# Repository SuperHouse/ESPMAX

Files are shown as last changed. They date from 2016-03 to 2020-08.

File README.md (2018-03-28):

ESP Max Prototyping Board
=========================

Copyright 2016 SuperHouse Automation Pty Ltd www.superhouse.tv  

Prototyping board for IoT projects using the ESP8266 microcontroller
on the ESP-12E module.

Features:

 * CP2102 USB-to-Serial converter.
 * 12 digital I/O channels at 3.3V.
 * 1 analog input with 0-3.2V range.
 * Power from USB or DC IN
 * 5V and 3.3V voltage regulators.
 * Jumper to select power source.
 * Prototyping area.
 * Expansion headers in D1 Mini format to suit expansion shields.

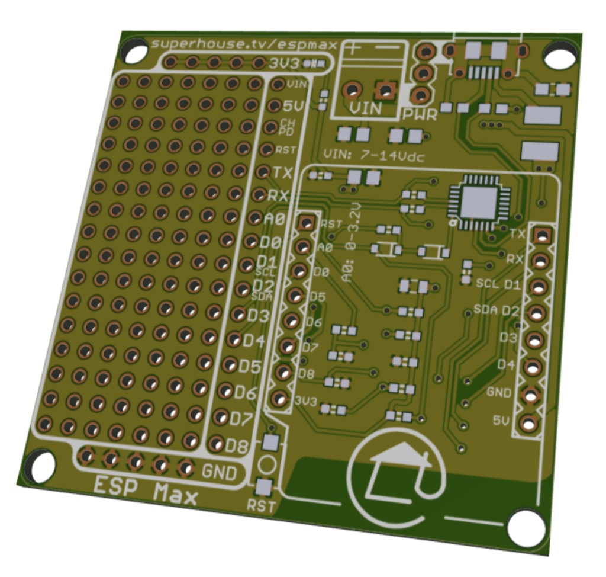
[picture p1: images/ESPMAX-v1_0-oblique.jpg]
Oblique view


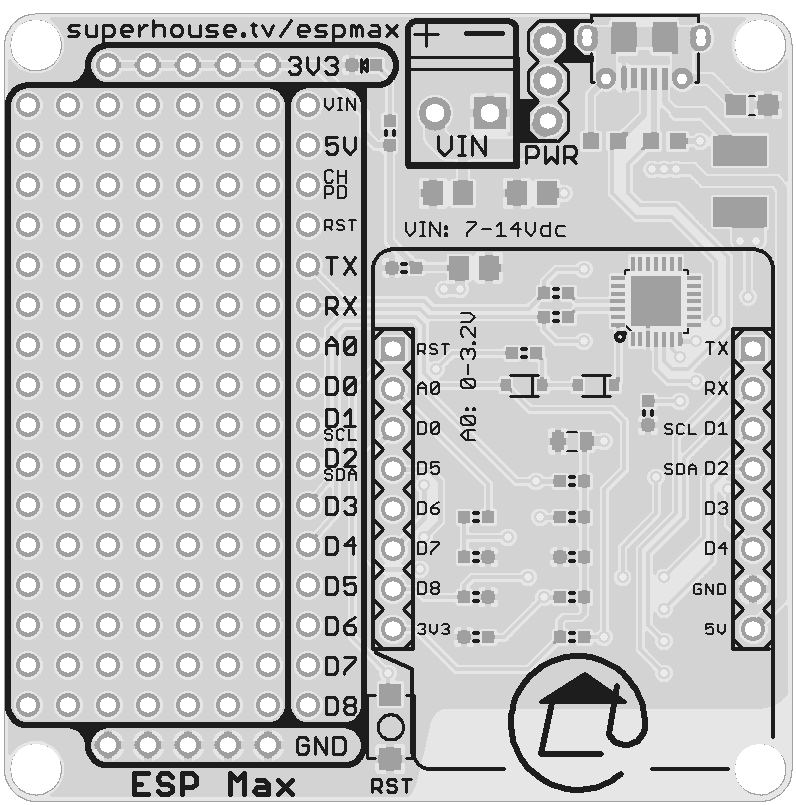
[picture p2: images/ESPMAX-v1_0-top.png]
Top view


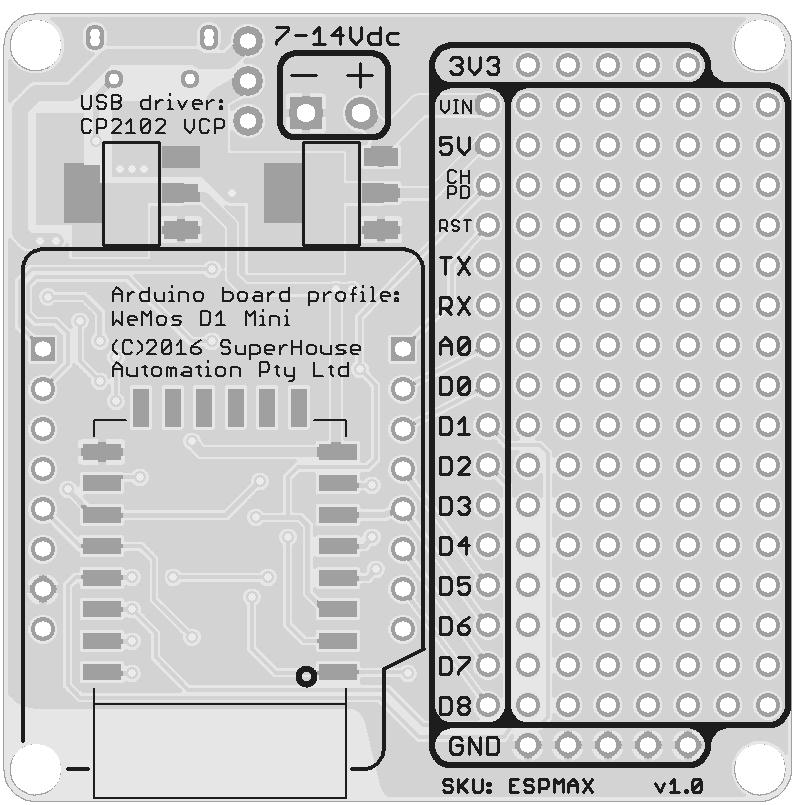
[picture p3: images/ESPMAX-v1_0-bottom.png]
Bottom view


More information is available at:

  http://www.superhouse.tv/espmax

INSTALLATION
------------
The design is saved as an EAGLE project. EAGLE PCB design software is
available from www.cadsoftusa.com free for non-commercial use. To use
this project download it and place the directory containing these files
into the "eagle" directory on your computer.

DISTRIBUTION
------------
The specific terms of distribution of this project are governed by the
license referenced below.

LICENSE
-------
Licensed under the TAPR Open Hardware License (www.tapr.org/OHL).
The "license" folder within this repository also contains a copy of
this license in plain text format.

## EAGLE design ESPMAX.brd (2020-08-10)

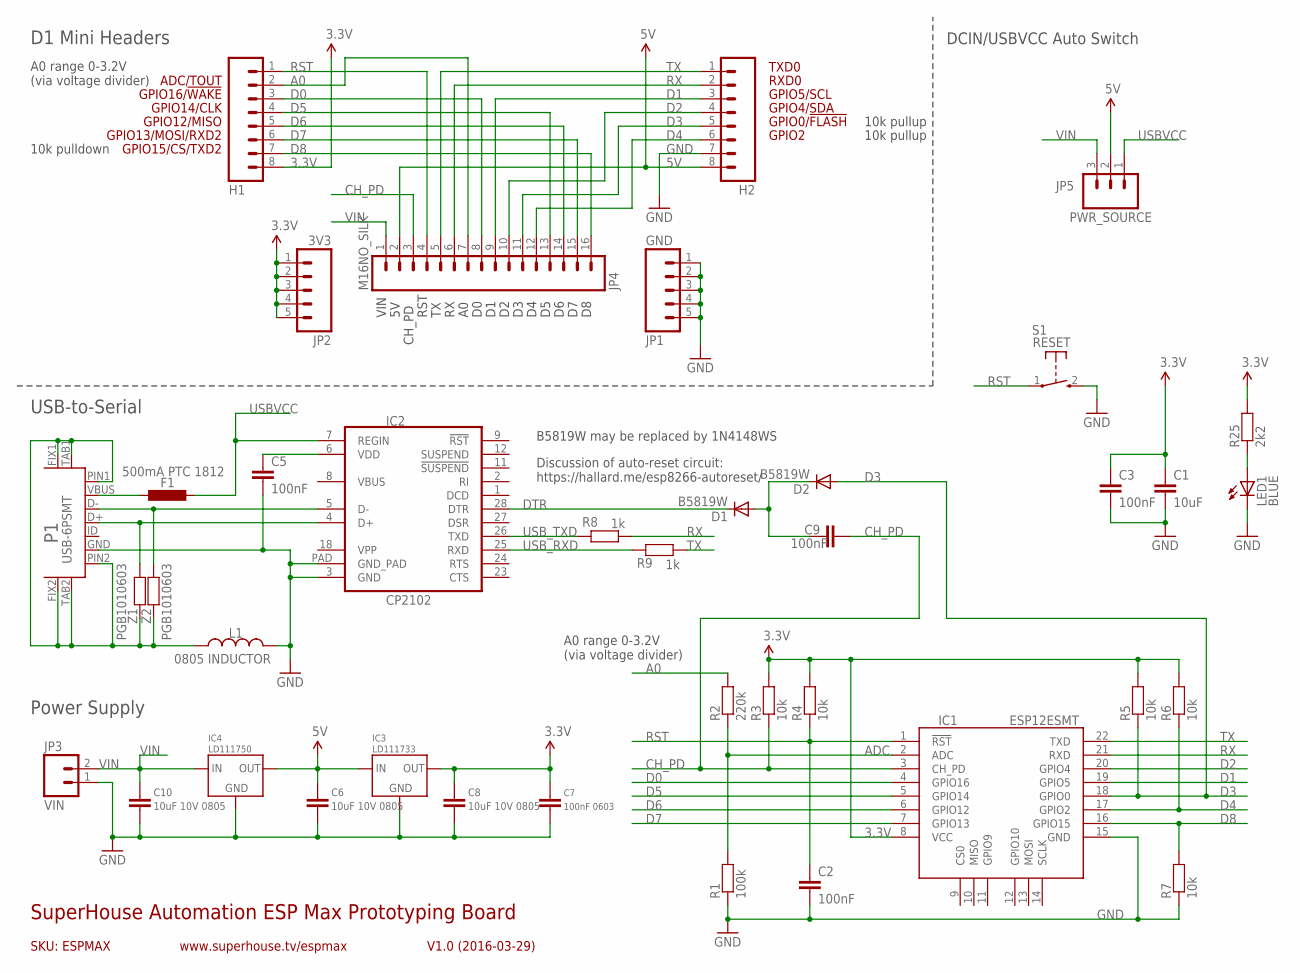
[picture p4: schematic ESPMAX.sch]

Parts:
C1: 10uF; 0805
C2, C3, C5, C9: 100nF; 0603
C6, C8, C10: 10uF 10V 0805; C0805
C7: 100nF 0603; 0603
D1, D2: B5819W; SOD-323
F1: 500mA PTC 1812; L1812
H1, H2: M08; 1X08
IC1: ESP12ESMT; ESP12E
IC2: CP2102; QFN-28
IC3: LD111733; SOT-223
IC4: LD111750; SOT-223
JP1: GND; 1X05_NO_SILK
JP2: 3V3; 1X05_NO_SILK
JP3: VIN; SCREWTERMINAL-3.5MM-2
JP4: M16NO_SILK; 1X16_NO_SILK
JP5: PWR_SOURCE; 1X03
L1: 0805 INDUCTOR; 0805-LARGE
LED1: BLUE; LED-0603
P1: USB-6PSMT; USB-MICROB-MB05PMXX
R1: 100k; 0603
R2: 220k; 0603
R3, R4, R5, R6, R7: 10k; 0603
R8, R9: 1k; 0603
R25: 2k2; 0603
S1: RESET; TACTILE_SWITCH_SMD_2PIN_TINY
Z1, Z2: PGB1010603; 0603

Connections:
3.3V: C1.1, C3.1, C7.1, C8.1, H1.8, IC1.8 (VCC), IC3.2 (OUT), IC3.4 (OUT), JP2.1, JP2.2, JP2.3, JP2.4, JP2.5, R3.2, R4.2, R5.2, R6.2, R25.2
5V: C6.1, H2.8, IC3.3 (IN), IC4.2 (OUT), IC4.4 (OUT), JP4.2, JP5.2
A0: H1.2, JP4.7, R2.2
ADC: IC1.2 (ADC), R1.2, R2.1
CH_PD: C9.2, IC1.3 (CH_PD), JP4.3, R3.1
D0: H1.3, IC1.4 (GPIO16), JP4.8
D1: H2.3, IC1.19 (GPIO5), JP4.9
D2: H2.4, IC1.20 (GPIO4), JP4.10
D3: D2.2 (A), H2.5, IC1.18 (GPIO0), JP4.11, R5.1
D4: H2.6, IC1.17 (GPIO2), JP4.12, R6.1
D5: H1.4, IC1.5 (GPIO14), JP4.13
D6: H1.5, IC1.6 (GPIO12), JP4.14
D7: H1.6, IC1.7 (GPIO13), JP4.15
D8: H1.7, IC1.16 (GPIO15), JP4.16, R7.2
DTR: D1.1 (C), IC2.28 (DTR)
GND: C1.2, C2.2, C3.2, C5.2, C6.2, C7.2, C8.2, C10.2, H2.7, IC1.15 (GND), IC2.3 (GND), IC2.PAD (GND_PAD), IC3.1 (GND), IC4.1 (GND), JP1.1, JP1.2, JP1.3, JP1.4, JP1.5, JP3.1, L1.2, LED1.C, P1.GND, R1.1, R7.1, S1.2 (S)
unnamed: LED1.A, R25.1
unnamed: C9.1, D1.2 (A), D2.1 (C)
unnamed: L1.1, P1.FIX1, P1.FIX2, P1.PIN1, P1.PIN2, P1.TAB1, P1.TAB2, Z1.2, Z2.2
unnamed: IC2.4 (D+), P1.D+, Z1.1
unnamed: IC2.5 (D-), P1.D-, Z2.1
unnamed: C5.1, IC2.6 (VDD)
unnamed: F1.1, P1.VBUS
RST: C2.1, H1.1, IC1.1 (!RST), JP4.4, R4.1, S1.1
RX: H2.2, IC1.21 (RXD), JP4.6, R8.1
TX: H2.1, IC1.22 (TXD), JP4.5, R9.1
USBVCC: F1.2, IC2.7 (REGIN), JP5.1
USB_RXD: IC2.25 (RXD), R9.2
USB_TXD: IC2.26 (TXD), R8.2
VIN: C10.1, IC4.3 (IN), JP3.2, JP4.1, JP5.3

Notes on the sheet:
SKU: ESPMAX
SuperHouse Automation ESP Max Prototyping Board
V1.0 (2016-03-29)
www.superhouse.tv/espmax
D1 Mini Headers
GPIO2
GPIO0/!FLASH
GPIO12/MISO
GPIO4/SDA
GPIO5/SCL
RXD0
TXD0
GPIO13/MOSI/RXD2
GPIO14/CLK
GPIO15/CS/TXD2
GPIO16/!WAKE
ADC/TOUT
10k pulldown
10k pullup
RST
Discussion of auto-reset circuit: https://hallard.me/esp8266-autoreset/
VIN
CH_PD
A0 range 0-3.2V (via voltage divider)
USB-to-Serial
Power Supply
B5819W may be replaced by 1N4148WS
DCIN/USBVCC Auto Switch

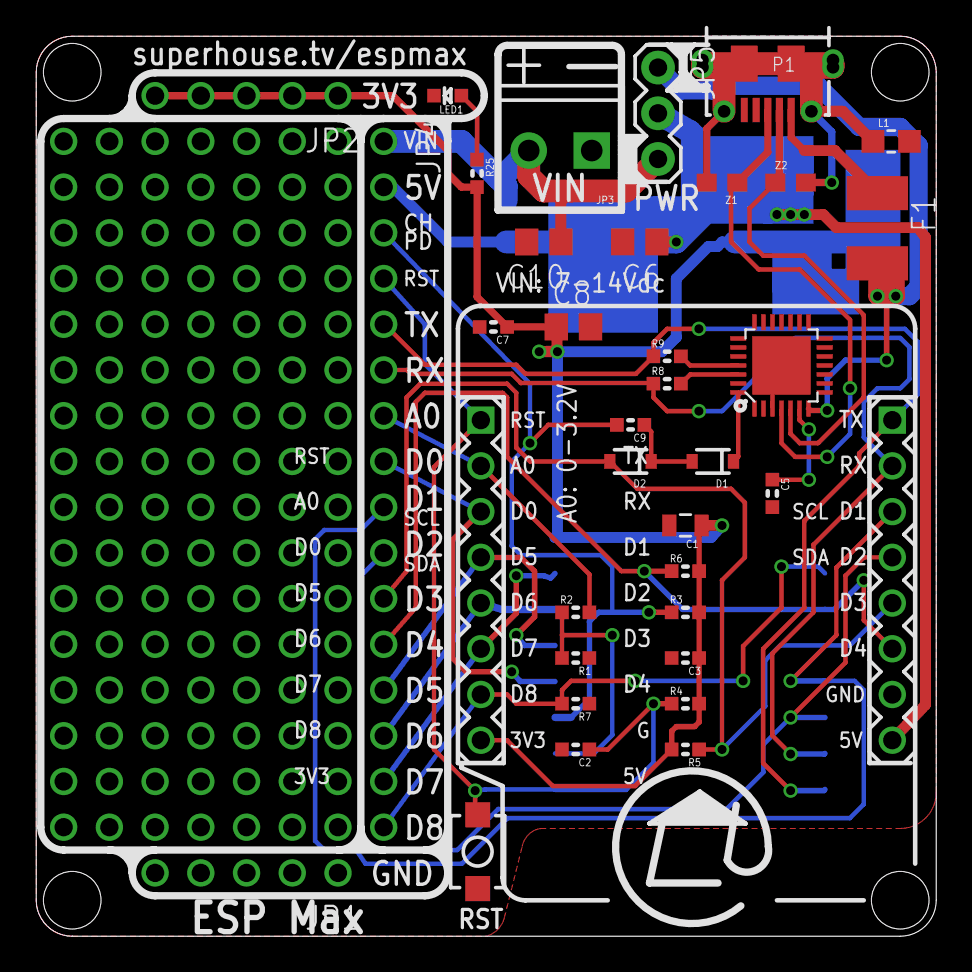
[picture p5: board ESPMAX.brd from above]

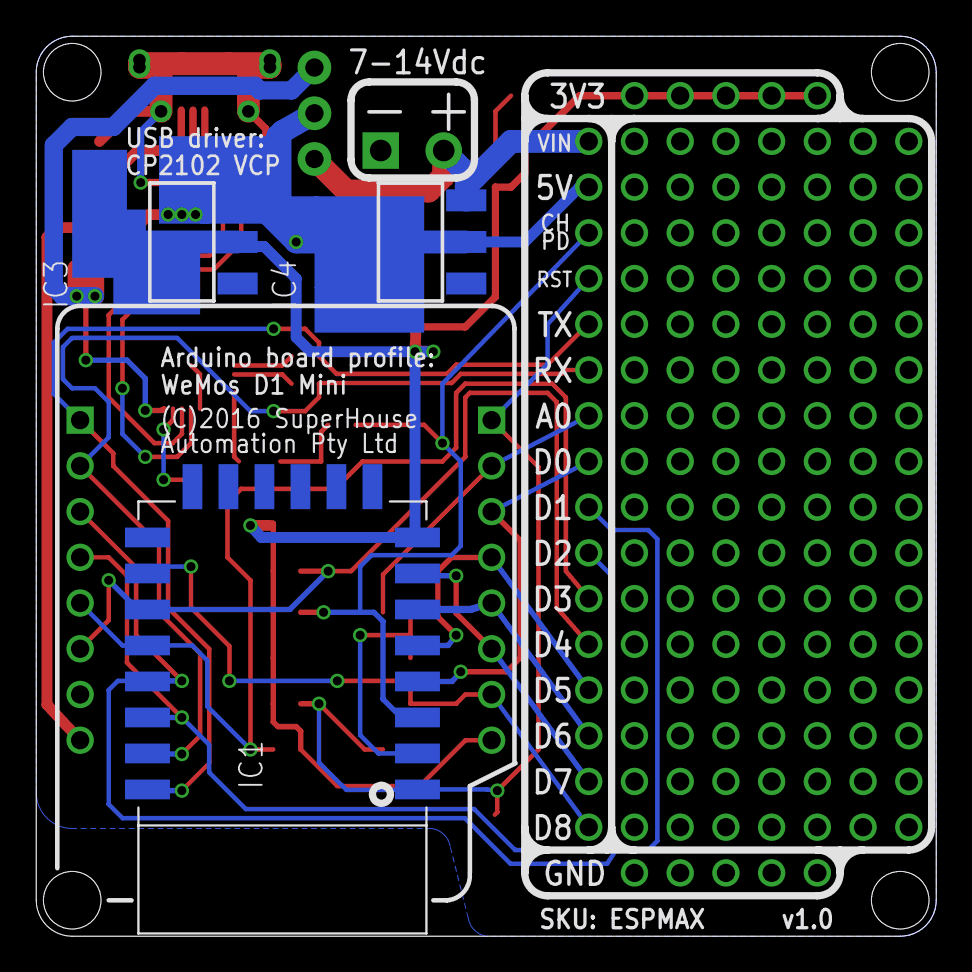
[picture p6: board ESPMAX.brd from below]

Board: 2 copper layers, 50.0 x 50.0 mm, 39 parts (3 on the bottom side), 30 nets.

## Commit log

2016-03-29 Initial import
    [ESPMAX.brd, ESPMAX.sch]
2018-03-28 Minor silkscreen improvements
    [ESPMAX.brd]
2020-08-10 Updated Eagle file format
    [ESPMAX.brd]

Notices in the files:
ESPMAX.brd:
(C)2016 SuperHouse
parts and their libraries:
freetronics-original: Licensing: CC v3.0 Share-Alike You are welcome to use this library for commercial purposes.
